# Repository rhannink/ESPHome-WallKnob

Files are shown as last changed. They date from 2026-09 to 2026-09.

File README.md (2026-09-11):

# ESPHome WallKnob-C6

Wall-mounted ESPHome rotary controller based on ESP32-C6, designed for a European flush-mount box and a Busch-Jaeger SI front.

## Rev A — frozen design basis

- Round PCB: **Ø58 mm**, 1.6 mm, 2-layer
- Rotary encoder shaft exactly at PCB geometric center
- **ESP32-C6-MINI-1**
- **EC11** incremental rotary encoder with push switch
- **Mean Well IRM-01-3.3** isolated 230 VAC → 3.3 V supply
- Status LED
- Programming/test pads
- On-board mains fuse
- Three mechanical mounting points
- Target installation depth: **40 mm**
- Busch-Jaeger SI-compatible front using the original frame/knob plus a 3D-printed adapter

Front side: encoder, ESP32-C6, status LED and programming pads.  
Rear side: IRM-01-3.3, fuse and AC input connector.

Rev A deliberately has **no** expansion header, relay, sensor, buzzer, RGB LED or extra buttons.

> **Safety:** This design contains hazardous mains voltage. Creepage/clearance, fusing, enclosure, insulation, PCB material, assembly and final installation must be verified against the applicable standards before connection to 230 VAC.

## Repository layout

- `hardware/` — Rev A mechanical/electrical design data
- `firmware/` — ESPHome configuration
- `docs/` — design notes, bring-up and safety checklist

## Current status

Rev A project baseline is now committed. The next hardware step is schematic capture and PCB routing while preserving the frozen mechanical constraints above.

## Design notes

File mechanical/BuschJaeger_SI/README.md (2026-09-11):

# WallKnob-C6 Rev A — Busch-Jaeger Reflex SI mechanical parts

These files form the first printable mechanical set for the WallKnob-C6.

## Parts

- `si_centerplate.scad/.stl` — 54 x 54 mm center plate for a Reflex SI single frame, with centered EC11 shaft opening.
- `pcb_carrier.scad/.stl` — carrier ring for the Ø58 mm Rev A PCB, with three mounting points.
- `ec11_knob.scad/.stl` — 30 mm knob for a common 6 mm D-shaft EC11 encoder.
- `assembly_preview.scad` — visual reference only; contains an 81 x 81 mm nominal frame placeholder.

## Known dimensions

Busch-Jaeger documentation specifies a 54 x 54 mm cover and 81 x 81 mm single frame for Reflex SI. The design uses those nominal dimensions as its interface envelope.

## Important before final print

Busch-Jaeger has several SI families/cover mechanisms. The outer visible dimensions are documented, but the exact retaining geometry behind the center plate depends on the physical part. Therefore Rev A currently uses a simple center plate geometry and separate PCB carrier. Measure your actual Reflex SI frame/cover and tune the OpenSCAD parameters before treating this as production-final.

Recommended first print: PETG, 0.20 mm layers, 3-4 walls. Print the center plate face-down only if your build plate gives a suitable visible finish; otherwise face-up with a fine top surface.

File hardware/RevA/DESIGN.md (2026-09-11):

# WallKnob-C6 Rev A design specification

## Mechanical

| Item | Rev A value |
|---|---|
| PCB | Round, Ø58.0 mm, 1.6 mm FR-4, 2-layer |
| Encoder axis | X=0, Y=0 / exact board center |
| Installation | European flush-mount wall box |
| Maximum target depth | 40 mm from front mounting plane |
| Front system | Busch-Jaeger SI frame/knob via adapter |
| Mounting | 3 × M2.5 holes, 120° apart, nominal radius 25 mm |

The encoder is the mechanical datum. Do not move it to solve routing problems.

## Functional blocks

### Mains input

230 VAC enters on the rear side through a 2-pole terminal. The mains section contains:

1. AC input terminal
2. time-lag fuse / fusible protection footprint
3. IRM-01-3.3 isolated AC/DC module
4. isolated SELV 3.3 V rail

Keep the primary copper region physically separated from SELV. No ground pour may bridge the isolation barrier. Add a routed isolation slot where practical between primary and secondary areas.

### MCU

ESP32-C6-MINI-1, powered directly from the isolated 3.3 V rail. Provide local 100 nF + bulk decoupling near the module supply pins. Keep the antenna end at the PCB edge with copper/component keep-out underneath and in front of the antenna according to the module integration guidance.

### Encoder

EC11 incremental encoder with push switch:

- A → GPIO with pull-up
- B → GPIO with pull-up
- SW → GPIO with pull-up
- common → GND

Place optional RC/debounce footprints close to the MCU/encoder signals. Firmware can provide the main debounce/filtering.

### Status LED

One low-current status LED driven from a GPIO through a series resistor.

### Programming / bring-up

Expose labeled test pads for:

- 3V3
- GND
- UART TX
- UART RX
- EN
- BOOT/GPIO9

These pads are low-voltage only and must remain in the SELV zone.

## Provisional GPIO assignment

The mapping below is intentionally centralized so it can be changed after the first KiCad/ERC pass without changing the functional design.

| Function | GPIO |
|---|---:|
| Encoder A | GPIO2 |
| Encoder B | GPIO3 |
| Encoder switch | GPIO4 |
| Status LED | GPIO5 |
| BOOT | GPIO9 |

GPIO choices must be checked against ESP32-C6 strapping/JTAG/USB constraints before manufacturing.

## PCB zoning

Rear side contains the mains connector, fuse and IRM-01-3.3. Front side contains the EC11, ESP32-C6, LED and low-voltage programming pads.

Use three explicit zones:

- PRIMARY: connector → fuse → IRM primary
- ISOLATION BARRIER: no copper/components except approved module boundary; add slot where feasible
- SELV: IRM secondary → MCU/encoder/LED/test pads

Do not route low-voltage traces through the primary area merely to shorten routing.

## Rev A DFM checks before ordering

- Verify exact IRM-01-3.3 footprint against current Mean Well drawing
- Verify exact EC11 variant body, shaft length and locating tabs
- Verify Busch-Jaeger SI adapter dimensions with physical parts
- Verify antenna keep-out
- Verify creepage/clearance for the intended installation category and pollution degree
- Verify fuse rating and interrupt capability
- Verify terminal voltage/current rating and wire accessibility
- Verify total assembled depth in a real flush-mount box
- Run ERC and DRC with explicit primary/SELV net classes
- Inspect Gerbers before fabrication

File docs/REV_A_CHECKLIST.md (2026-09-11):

# Rev A checklist

## Mechanical

- [ ] PCB Ø58.0 mm
- [ ] EC11 shaft exactly centered
- [ ] Three mounting holes checked against adapter
- [ ] Busch-Jaeger SI frame/knob fit checked physically
- [ ] Total installed depth ≤ 40 mm target
- [ ] No rear component collides with wall box or wiring

## Primary / mains

- [ ] IRM-01-3.3 footprint checked against manufacturer drawing
- [ ] Primary and SELV zones visibly separated
- [ ] Required creepage/clearance established from applicable standard
- [ ] Isolation slot added/checked where feasible
- [ ] Fuse type/rating/interrupt capability selected
- [ ] Terminal approved for intended mains wiring
- [ ] No exposed primary copper accessible after assembly

## SELV / MCU

- [ ] ESP32-C6-MINI-1 footprint and antenna orientation checked
- [ ] Antenna copper/component keep-out checked
- [ ] GPIO mapping checked for strapping/debug conflicts
- [ ] 3.3 V decoupling checked
- [ ] Encoder A/B/SW pull-ups checked
- [ ] Programming pads labeled and accessible

## CAD release

- [ ] ERC clean or all exceptions documented
- [ ] DRC clean or all exceptions documented
- [ ] 3D board inspection complete
- [ ] Gerber viewer inspection complete
- [ ] Drill files inspected
- [ ] BOM generated
- [ ] Pick-and-place generated if assembly is outsourced

## First power-up

Do not connect an unverified prototype directly to mains on the bench. First inspect continuity/isolation and power the SELV side from a current-limited isolated 3.3 V supply for MCU/firmware bring-up. Mains-side validation requires appropriate qualified procedures and test equipment.

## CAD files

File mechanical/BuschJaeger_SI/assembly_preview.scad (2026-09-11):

// Visual-only assembly preview for WallKnob-C6 + Reflex SI front
use <si_centerplate.scad>
use <pcb_carrier.scad>

module frame_preview(){
  difference(){
    color("white") linear_extrude(6) offset(r=3) square([75,75],center=true);
    translate([0,0,-0.1]) linear_extrude(6.2) offset(r=2.5) square([54.8,54.8],center=true);
  }
}
frame_preview();
translate([0,0,1.5]) color("ivory") rounded_square(54,2.4,2.2);
translate([0,0,-5]) color("gray") cylinder(d=58,h=1.6);
translate([0,0,-9]) color("orange") difference(){cylinder(d=66,h=3); cylinder(d=58.6,h=3.2);}

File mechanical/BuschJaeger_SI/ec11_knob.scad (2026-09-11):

// WallKnob-C6 Rev A - printable knob for common 6 mm D-shaft EC11
$fn=120;
knob_d=30;
knob_h=14;
bore_d=6.15;
shaft_flat=4.5;
bore_depth=11.5;

module d_bore(h){
  intersection(){
    cylinder(d=bore_d,h=h);
    translate([-bore_d,-bore_d,0]) cube([2*bore_d, bore_d+shaft_flat, h]);
  }
}

difference(){
  union(){
    cylinder(d=knob_d,h=knob_h);
    for(a=[0:15:345]) rotate([0,0,a]) translate([knob_d/2-0.4,0,knob_h/2]) cube([0.8,1.2,knob_h],center=true);
  }
  translate([0,0,-0.1]) d_bore(bore_depth+0.1);
  translate([0,knob_d/2-4,knob_h-0.6]) cylinder(d=2.2,h=0.8);
}

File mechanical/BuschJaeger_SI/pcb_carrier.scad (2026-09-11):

// WallKnob-C6 Rev A - PCB carrier for Ø58 mm board
// Supports PCB at 3 points, matching Rev A mounting holes (radius 24 mm, 120 degrees)
$fn=96;
outer_d=66;
inner_d=58.6;
carrier_h=3.0;
ear_r=4.5;
hole_d=2.8;
mount_r=24;

module ear(a){
  rotate([0,0,a]) translate([mount_r,0,0]) cylinder(r=ear_r,h=carrier_h);
}

difference(){
  union(){
    difference(){
      cylinder(d=outer_d,h=carrier_h);
      translate([0,0,-0.1]) cylinder(d=inner_d,h=carrier_h+0.2);
    }
    ear(-90); ear(30); ear(150);
  }
  for(a=[-90,30,150])
    rotate([0,0,a]) translate([mount_r,0,-0.1]) cylinder(d=hole_d,h=carrier_h+0.2);
}

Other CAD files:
mechanical/BuschJaeger_SI/si_centerplate.scad

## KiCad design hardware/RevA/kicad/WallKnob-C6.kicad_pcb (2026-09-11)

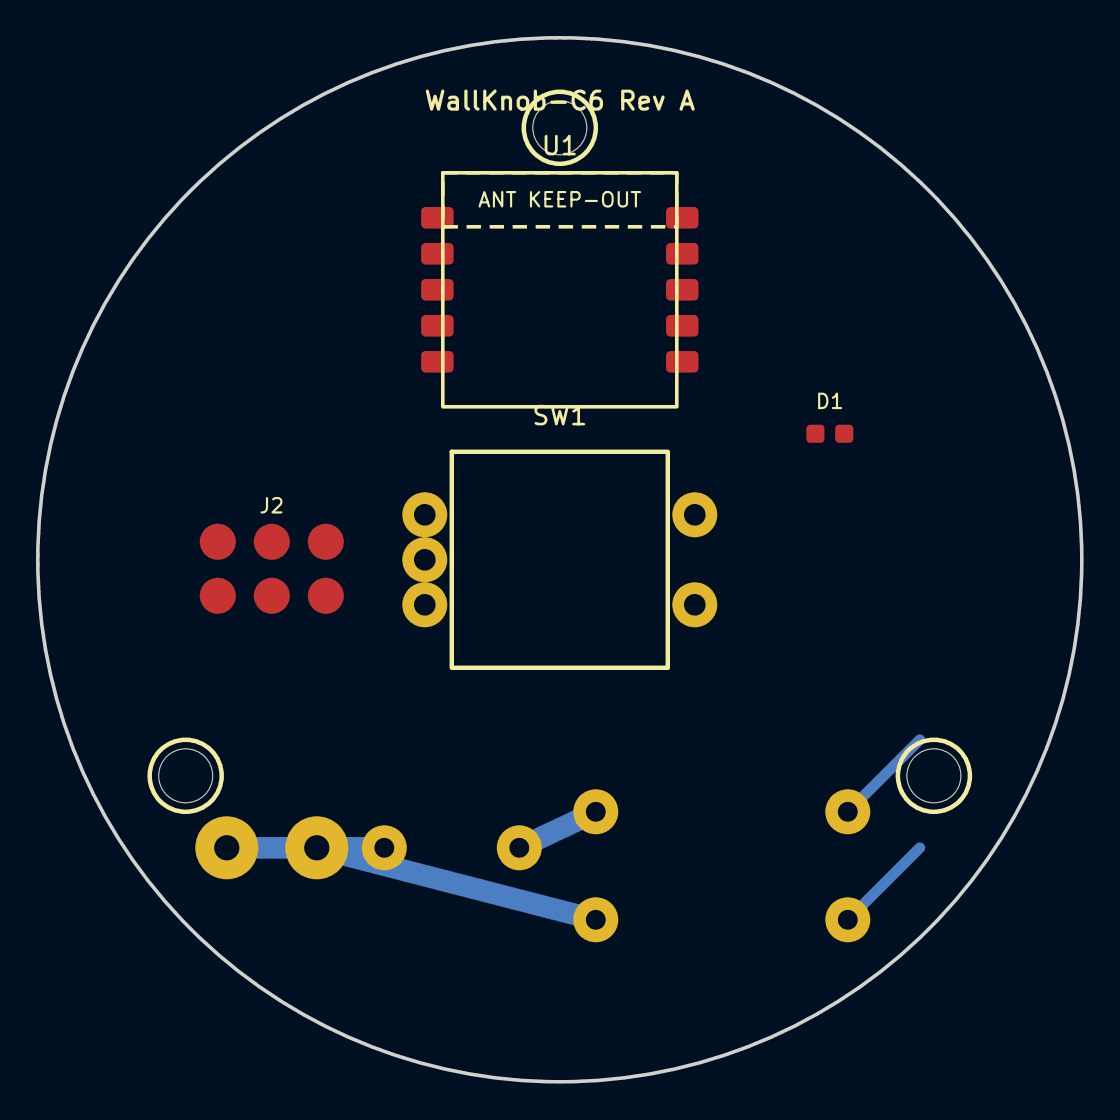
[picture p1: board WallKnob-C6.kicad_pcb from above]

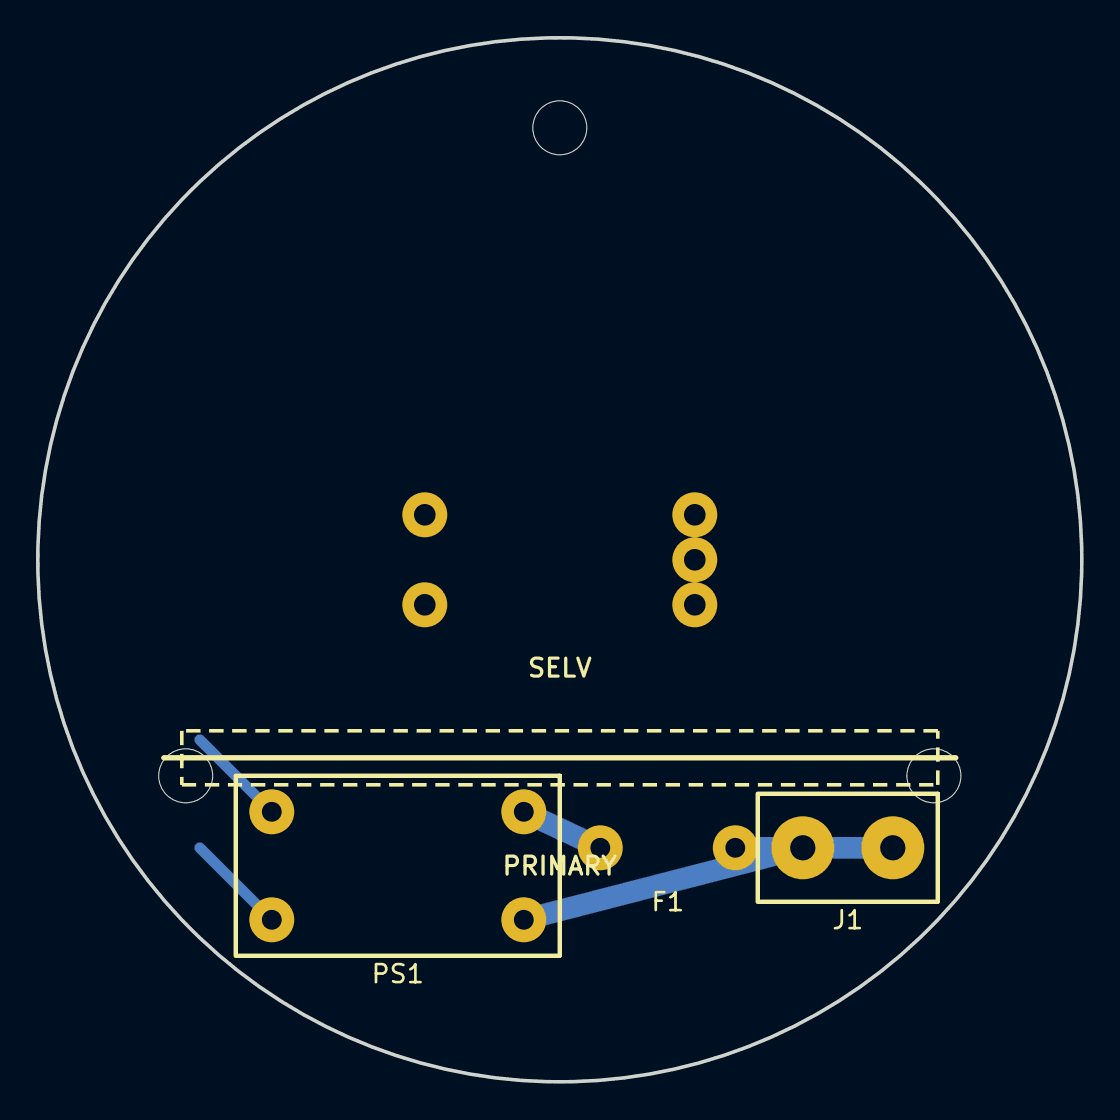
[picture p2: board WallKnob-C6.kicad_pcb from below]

Board: 2 copper layers, 58.0 x 58.0 mm, 10 parts (3 on the bottom side), 13 nets.

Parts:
D1: LED_0603
F1: FUSE_THT_CUSTOM
H1: MountingHole_1
H2: MountingHole_2
H3: MountingHole_3
J1: AC_IN_2P_CUSTOM
J2: TESTPADS_6
PS1: IRM-01-3.3 VERIFY FOOTPRINT; IRM-01-3.3_CUSTOM_VERIFY
SW1: EC11+PUSH; EC11_CUSTOM
U1: ESP32-C6-MINI-1; ESP32-C6-MINI-1_CUSTOM

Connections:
+3V3: J2.1, PS1.+V, U1.1
BOOT: J2.6, U1.8
EN: J2.5, U1.3
ENC_A: SW1.A, U1.4
ENC_B: SW1.B, U1.5
ENC_SW: SW1.S1, U1.6
GND: D1.2, J2.2, PS1.-V, SW1.C, SW1.S2, U1.2
LED: D1.1, U1.7
L_FUSED: F1.2, PS1.AC/L
L_IN: F1.1, J1.1
N_IN: J1.2, PS1.AC/N
UART_RX: J2.4, U1.10
UART_TX: J2.3, U1.9

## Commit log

2026-09-11 Add KiCad Rev A project container
2026-09-11 Add KiCad Rev A usage notes
2026-09-11 Add WallKnob-C6 Rev A PCB seed
    [WallKnob-C6.kicad_pcb]
2026-09-11 Add WallKnob-C6 Rev A schematic seed
    [WallKnob-C6.sch]
2026-09-11 Fix Rev A component placement inside PCB outline
    [WallKnob-C6.kicad_pcb]
2026-09-11 Add Reflex SI center plate OpenSCAD model
    [si_centerplate.scad]
2026-09-11 Add WallKnob PCB carrier OpenSCAD model
    [pcb_carrier.scad]
2026-09-11 Add EC11 printable knob OpenSCAD model
    [ec11_knob.scad]
2026-09-11 Add Reflex SI WallKnob assembly preview
    [assembly_preview.scad]
